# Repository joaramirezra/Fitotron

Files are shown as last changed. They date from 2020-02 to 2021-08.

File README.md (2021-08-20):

# Recamara de ambiente Controlado para germinar semillas de cannabis(Fitotron) 
### version : 0.2
### Fecha : 01/08/2021

**Antecedentes:** En el marco de la discusión de la propuesta del proyecto de ley sobre  regulación del consumo de cannabis con usos recreativo en Colombia, se han desarrollado debates en variados ámbitos algunos versan alrededor del cultivo,iacto economico, social, cultural  entre otros, por lo anterior se desarrolla un sistema de germinacion de semillas de cannabis, para poder impactar de manera positiva las primeras fases de la planta y con ellos contribuir en fases posteriores de crecimiento y cosecha.

**Descripción:**

### Requerimientos

**Hardware:**

- [ESP 8266](https://www.espressif.com/sites/default/files/documentation/0a-esp8266ex_datasheet_en.pdf)
- [Driver Actuadores](http://www.ti.com/lit/ds/symlink/uln2003a.pdf)
- [Sensor Humedad](https://www.sparkfun.com/datasheets/Sensors/Temperature/DHT22.pdf)
- [Raspberry pi]()

**Software:**

- [kicad 5.1.2](https://kicad-pcb.org/download/)
- [inventor 2019](https://www.autodesk.com/education/free-software/inventor-professional)
- [Arduino 18.1](https://www.arduino.cc/en/main/software)

### Colaboradores:
- [Johan Ramirez](https://github.com/joaramirezra)
- [Julio Cárdenas](https://github.com/julio-cardenas)

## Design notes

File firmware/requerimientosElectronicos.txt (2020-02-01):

Procesador : ESP32
Actuadores: 2 humidificadores 5Vdc, 12 ventiadores 12Vdc, 
	    6 luces led 12Vdc, 2 motobombas 12 Vdc, 1 resistencias de 
	    calentamiento 120 Vac
Sensores: 3 dht22 -> temperatura y humedad del aire 5V o 3.3Vdc
	  3 MQ135  -> dioxido de carbono 5 Vdc
	  2 SH2 -> sensor humedad del suelo 3.3Vdc
	  * deben poder encenderse y apagarse en la medición

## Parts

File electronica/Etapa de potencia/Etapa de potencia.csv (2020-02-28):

Reference(s) | Value | LibPart | Footprint
C1 | 100nF | Device:C_Small | Capacitor_SMD:C_0805_2012Metric_Pad1.15x1.40mm_HandSolder
C2, C3 | 10uF | Device:C_Small | Capacitor_SMD:C_0805_2012Metric_Pad1.15x1.40mm_HandSolder
D1 | BTA16 | Device:Q_TRIAC_A1A2G | Package_TO_SOT_THT:TO-220-3_Horizontal_TabDown
J1, J2 | Bornera Resorte | Connector_Generic:Conn_01x08 | potenciaFootprints:BorneraKF141R_8Pins
J3 | Bornera Resorte | Connector_Generic:Conn_01x04 | potenciaFootprints:BorneraKF141R_4Pins
J4 | Bornera 4 pines | Connector:Screw_Terminal_01x04 | TerminalBlock:TerminalBlock_Altech_AK300-4_P5.00mm
J5 | Header | Connector_Generic:Conn_01x04 | Connector_PinHeader_2.54mm:PinHeader_1x04_P2.54mm_Vertical
Q1, Q2, Q3 | MMBT2222 | Transistor_BJT:MMBT3904 | Package_TO_SOT_SMD:SOT-23
R1 | 10K | Device:R_US | Resistor_SMD:R_0805_2012Metric_Pad1.15x1.40mm_HandSolder
R2 | 470 | Device:R_US | Resistor_SMD:R_0805_2012Metric_Pad1.15x1.40mm_HandSolder
R3, R4, R5 | 1K | Device:R_US | Resistor_SMD:R_0805_2012Metric_Pad1.15x1.40mm_HandSolder
R6 | 100 | Device:R_US | Resistor_THT:R_Axial_DIN0411_L9.9mm_D3.6mm_P12.70mm_Horizontal
U1 | ATmega328-PU | MCU_Microchip_ATmega:ATmega328-PU | Package_DIP:DIP-28_W7.62mm
U2, U3 | ULN2003 | Transistor_Array:ULN2003 | Package_SO:SOIC-16W_5.3x10.2mm_P1.27mm
U4 | MOC3031M | Relay_SolidState:MOC3031M | Package_DIP:DIP-6_W7.62mm_LongPads
Y1 | Crystal | Device:Crystal | Crystal:Crystal_SMD_0603-2Pin_6.0x3.5mm

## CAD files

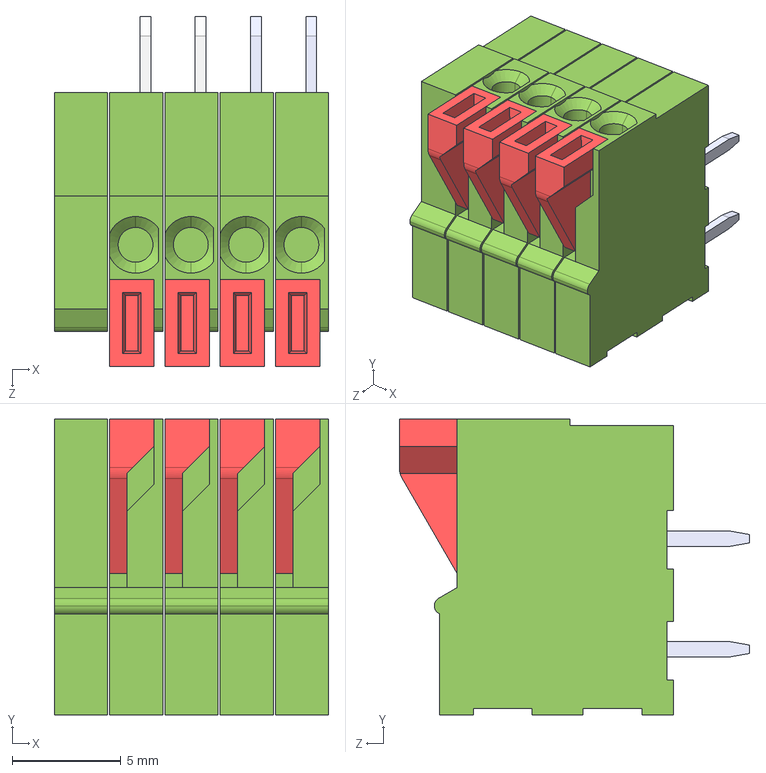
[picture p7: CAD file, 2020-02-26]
electronica/Etapa de potencia/User Library-DG141R-4-2_54.STEP
12.6 x 13.6 x 16.1 mm

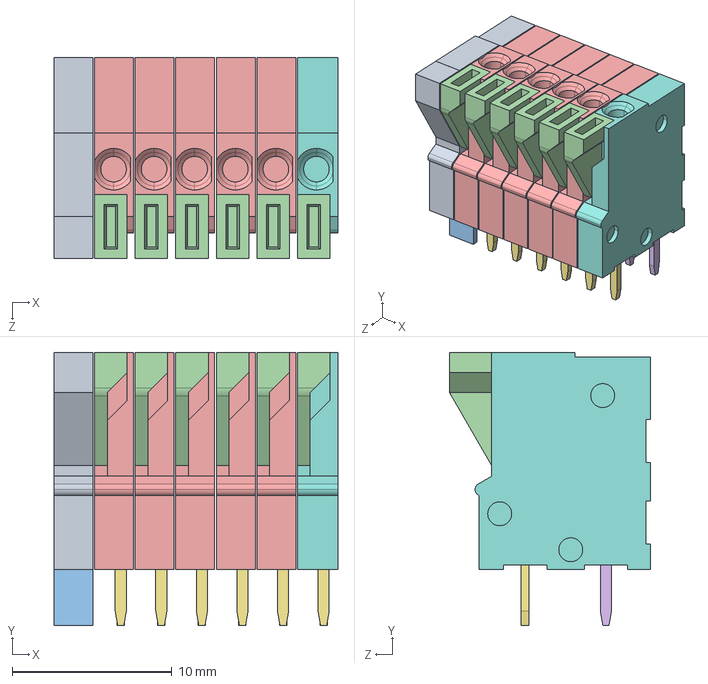
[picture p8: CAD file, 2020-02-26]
electronica/Etapa de potencia/DG141V-4-2.54.STEP
17.8 x 17.1 x 12.6 mm

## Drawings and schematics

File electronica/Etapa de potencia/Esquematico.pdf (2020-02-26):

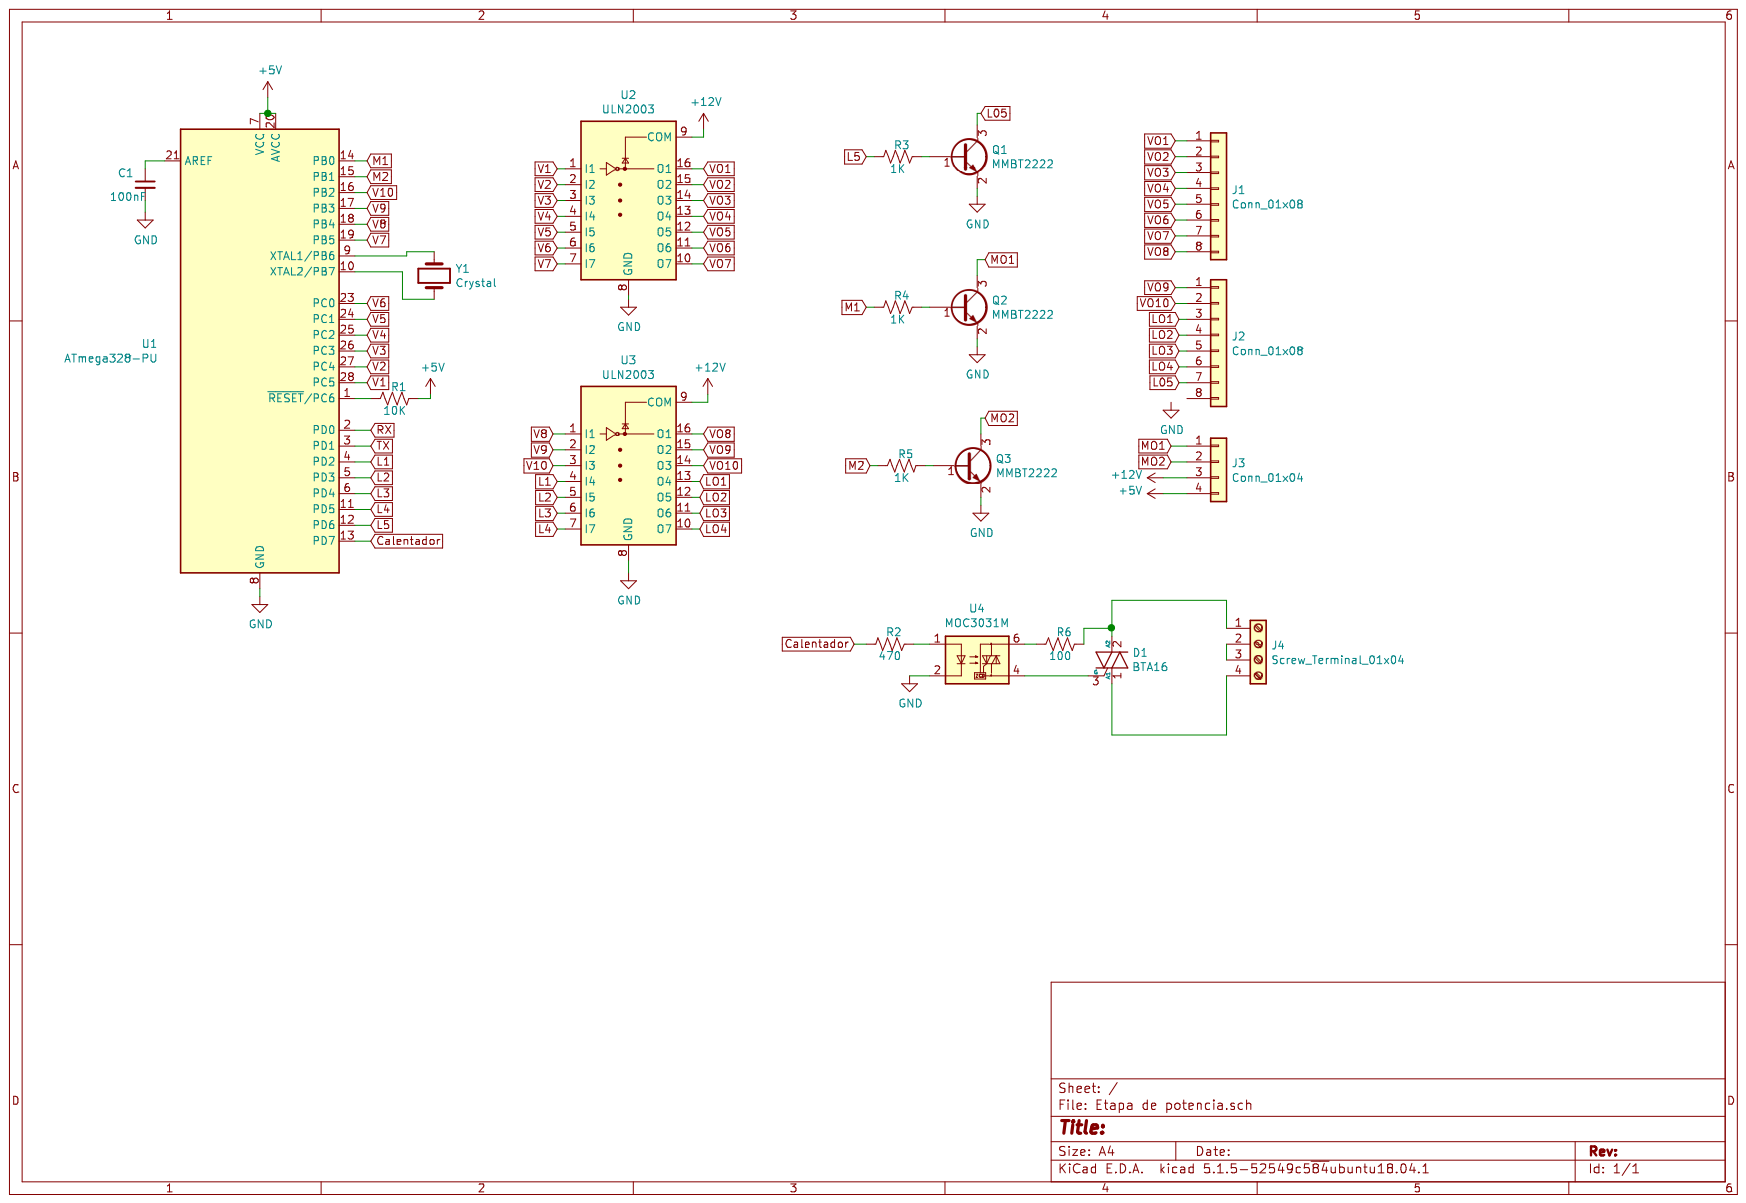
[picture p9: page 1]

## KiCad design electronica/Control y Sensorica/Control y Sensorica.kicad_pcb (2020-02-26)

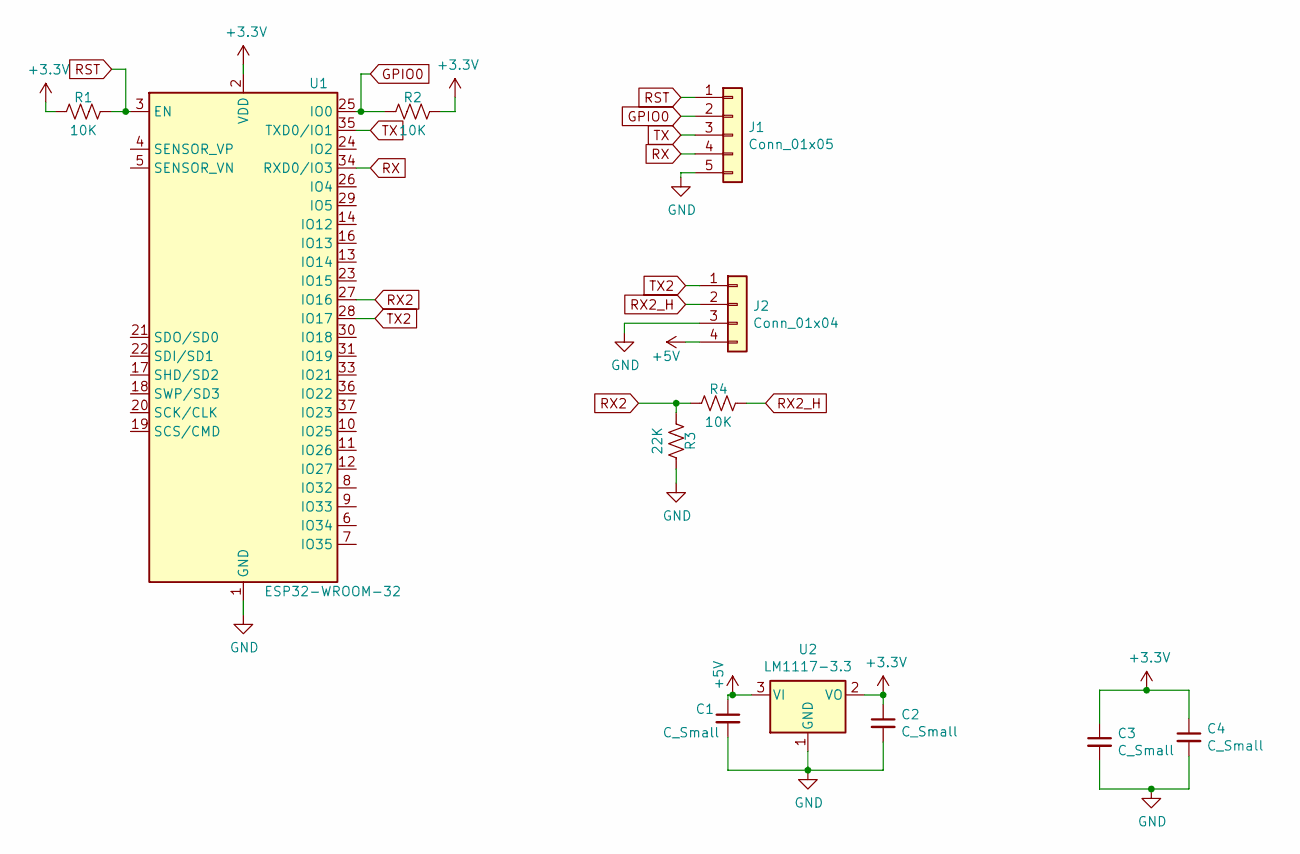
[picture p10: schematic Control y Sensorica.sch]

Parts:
C1, C2, C3, C4: C_Small; C_0805_2012Metric_Pad1.15x1.40mm_HandSolder
J1: Conn_01x05; PinHeader_1x05_P2.54mm_Horizontal
J2: Conn_01x04; PinSocket_1x04_P2.54mm_Vertical
R1, R2, R4: 10K; R_0805_2012Metric_Pad1.15x1.40mm_HandSolder
R3: 22K; R_0805_2012Metric_Pad1.15x1.40mm_HandSolder
U1: ESP32-WROOM-32
U2: LM1117-3.3; TO-252-2

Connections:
+3V3: C2.1, C3.1, C4.1, R1.2, R2.1, U1.2 (VDD), U2.2 (VO)
+5V: C1.1, J2.4, U2.3 (VI)
GND: C1.2, C2.2, C3.2, C4.2, J1.5, J2.3, R3.1, U1.1 (GND), U1.15 (GND), U1.38 (GND), U1.39 (GND), U2.1 (GND)
GPIO0: J1.2, R2.2, U1.25 (IO0)
RST: J1.1, R1.1, U1.3 (EN)
RX: J1.4, U1.34 (RXD0/IO3)
RX2: R3.2, R4.2, U1.27 (IO16)
RX2_H: J2.2, R4.1
TX: J1.3, U1.35 (TXD0/IO1)
TX2: J2.1, U1.28 (IO17)

Board: 2 copper layers, 12 parts (0 on the bottom side), 10 nets, no tracks yet.

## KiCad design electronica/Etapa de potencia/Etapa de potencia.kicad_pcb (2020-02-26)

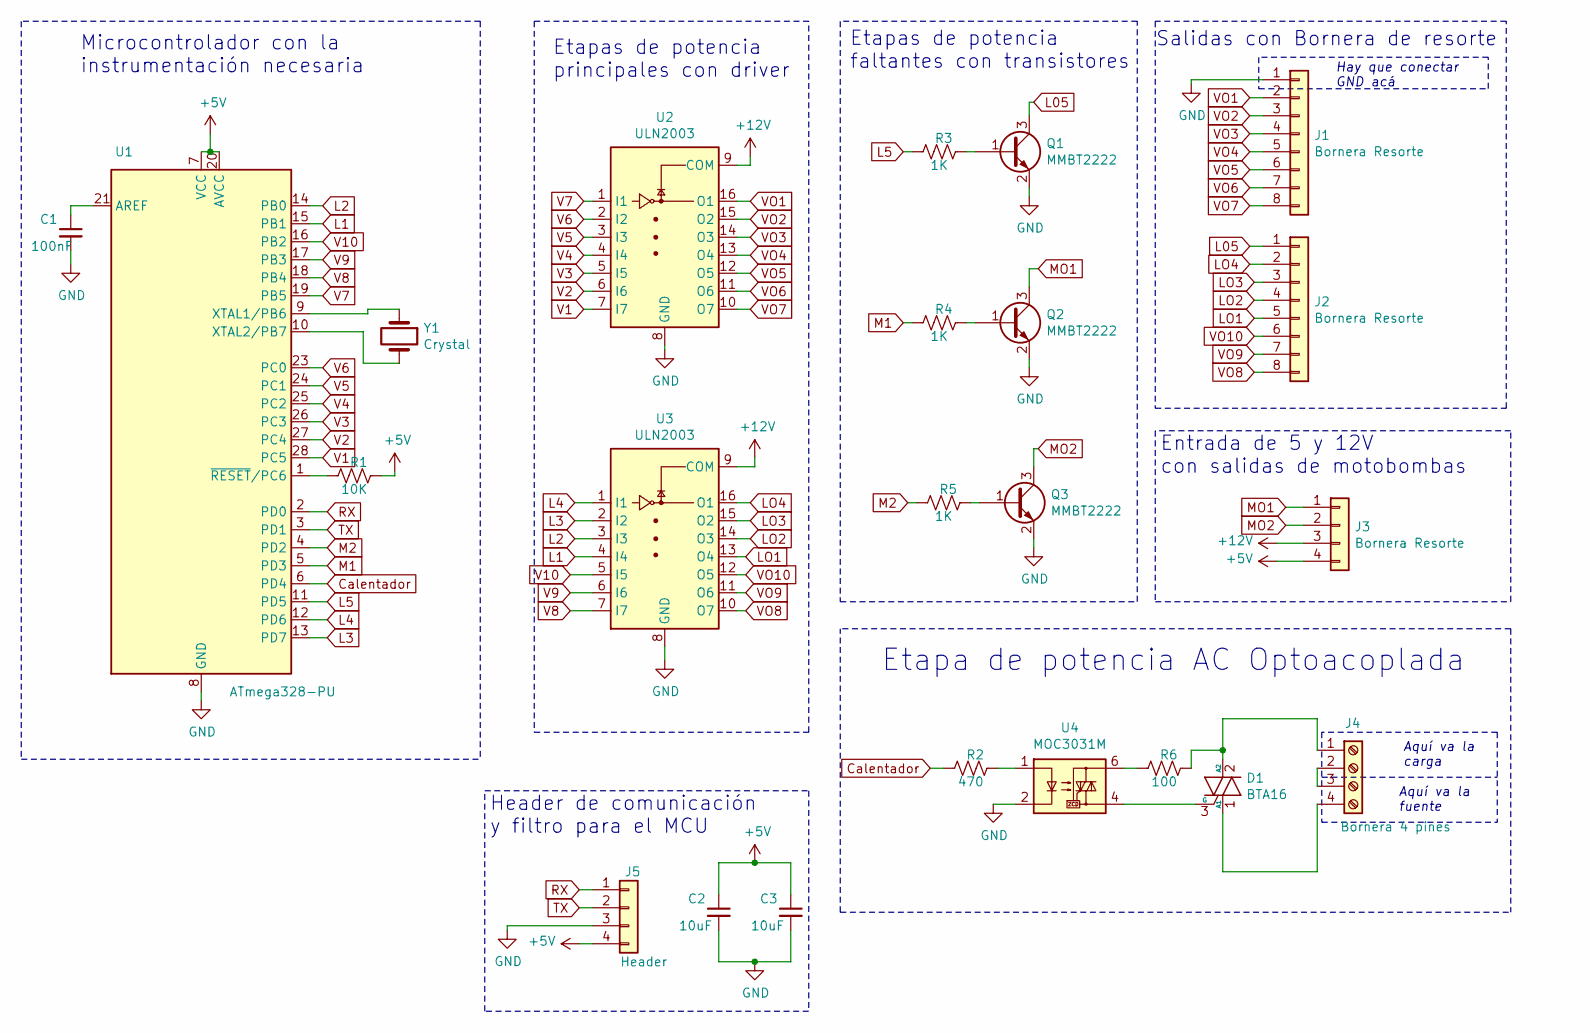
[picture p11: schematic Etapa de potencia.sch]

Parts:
C1: 100nF; C_0805_2012Metric_Pad1.15x1.40mm_HandSolder
C2, C3: 10uF; C_0805_2012Metric_Pad1.15x1.40mm_HandSolder
D1: BTA16; TO-220-3_Horizontal_TabDown
J1, J2: Bornera Resorte; BorneraKF141R_8Pins
J3: Bornera Resorte; BorneraKF141R_4Pins
J4: Bornera 4 pines; TerminalBlock_Altech_AK300-4_P5.00mm
J5: Header; PinHeader_1x04_P2.54mm_Vertical
Q1, Q2, Q3: MMBT2222; SOT-23
R1: 10K; R_0805_2012Metric_Pad1.15x1.40mm_HandSolder
R2: 470; R_0805_2012Metric_Pad1.15x1.40mm_HandSolder
R3, R4, R5: 1K; R_0805_2012Metric_Pad1.15x1.40mm_HandSolder
R6: 100; R_Axial_DIN0411_L9.9mm_D3.6mm_P12.70mm_Horizontal
U1: ATmega328-PU; DIP-28_W7.62mm
U2, U3: ULN2003; SOIC-16W_5.3x10.2mm_P1.27mm
U4: MOC3031M; DIP-6_W7.62mm_LongPads
Y1: Crystal; Crystal_SMD_0603-2Pin_6.0x3.5mm

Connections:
+5V: C2.1, C3.1, J3.4, J5.4, R1.1, U1.7 (VCC), U1.20 (AVCC)
+12V: J3.3, U2.9 (COM), U3.9 (COM)
Calentador: R2.2, U1.6 (PD4)
GND: C1.2, C2.2, C3.2, J1.1, J5.3, Q1.2 (E), Q2.2 (E), Q3.2 (E), U1.8 (GND), U1.22 (GND), U2.8 (GND), U3.8 (GND), U4.2
L1: U1.15 (PB1), U3.4 (I4)
L2: U1.14 (PB0), U3.3 (I3)
L3: U1.13 (PD7), U3.2 (I2)
L4: U1.12 (PD6), U3.1 (I1)
L05: J2.1, Q1.3 (C)
L5: R3.2, U1.11 (PD5)
LO1: J2.5, U3.13 (O4)
LO2: J2.4, U3.14 (O3)
LO3: J2.3, U3.15 (O2)
LO4: J2.2, U3.16 (O1)
M1: R4.2, U1.5 (PD3)
M2: R5.2, U1.4 (PD2)
MO1: J3.1, Q2.3 (C)
MO2: J3.2, Q3.3 (C)
unnamed: C1.1, U1.21 (AREF)
unnamed: D1.1 (A1), J4.4
unnamed: D1.2 (A2), J4.1, R6.1
unnamed: D1.3 (G), U4.4
unnamed: J4.2, J4.3
unnamed: Q1.1 (B), R3.1
unnamed: Q2.1 (B), R4.1
unnamed: Q3.1 (B), R5.1
unnamed: R1.2, U1.1 (~RESET~/PC6)
unnamed: R2.1, U4.1
unnamed: R6.2, U4.6
unnamed: U1.9 (XTAL1/PB6), Y1.1
unnamed: U1.10 (XTAL2/PB7), Y1.2
RX: J5.1, U1.2 (PD0)
TX: J5.2, U1.3 (PD1)
V1: U1.28 (PC5), U2.7 (I7)
V2: U1.27 (PC4), U2.6 (I6)
V3: U1.26 (PC3), U2.5 (I5)
V4: U1.25 (PC2), U2.4 (I4)
V5: U1.24 (PC1), U2.3 (I3)
V6: U1.23 (PC0), U2.2 (I2)
V7: U1.19 (PB5), U2.1 (I1)
V8: U1.18 (PB4), U3.7 (I7)
V9: U1.17 (PB3), U3.6 (I6)
V10: U1.16 (PB2), U3.5 (I5)
VO1: J1.2, U2.16 (O1)
VO2: J1.3, U2.15 (O2)
VO3: J1.4, U2.14 (O3)
VO4: J1.5, U2.13 (O4)
VO5: J1.6, U2.12 (O5)
VO6: J1.7, U2.11 (O6)
VO7: J1.8, U2.10 (O7)
VO8: J2.8, U3.10 (O7)
VO9: J2.7, U3.11 (O6)
VO10: J2.6, U3.12 (O5)

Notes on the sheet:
Etapa de potencia AC Optoacoplada
Salidas con Bornera de resorte
Hay que conectar GND acá
Entrada de 5 y 12V con salidas de motobombas
Etapas de potencia faltantes con transistores
Etapas de potencia principales con driver
Aquí va la fuente
Aquí va la carga
Microcontrolador con la instrumentación necesaria
Header de comunicación y filtro para el MCU

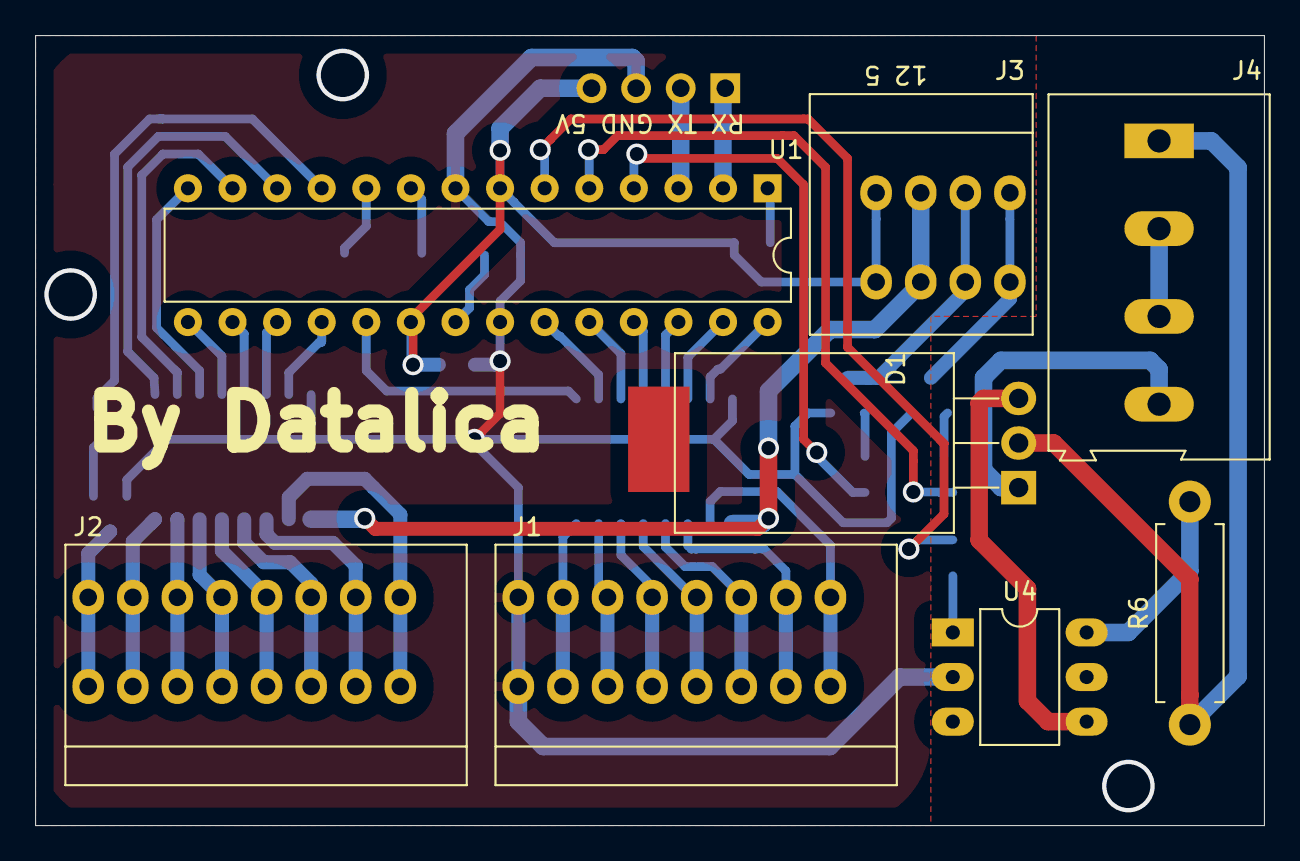
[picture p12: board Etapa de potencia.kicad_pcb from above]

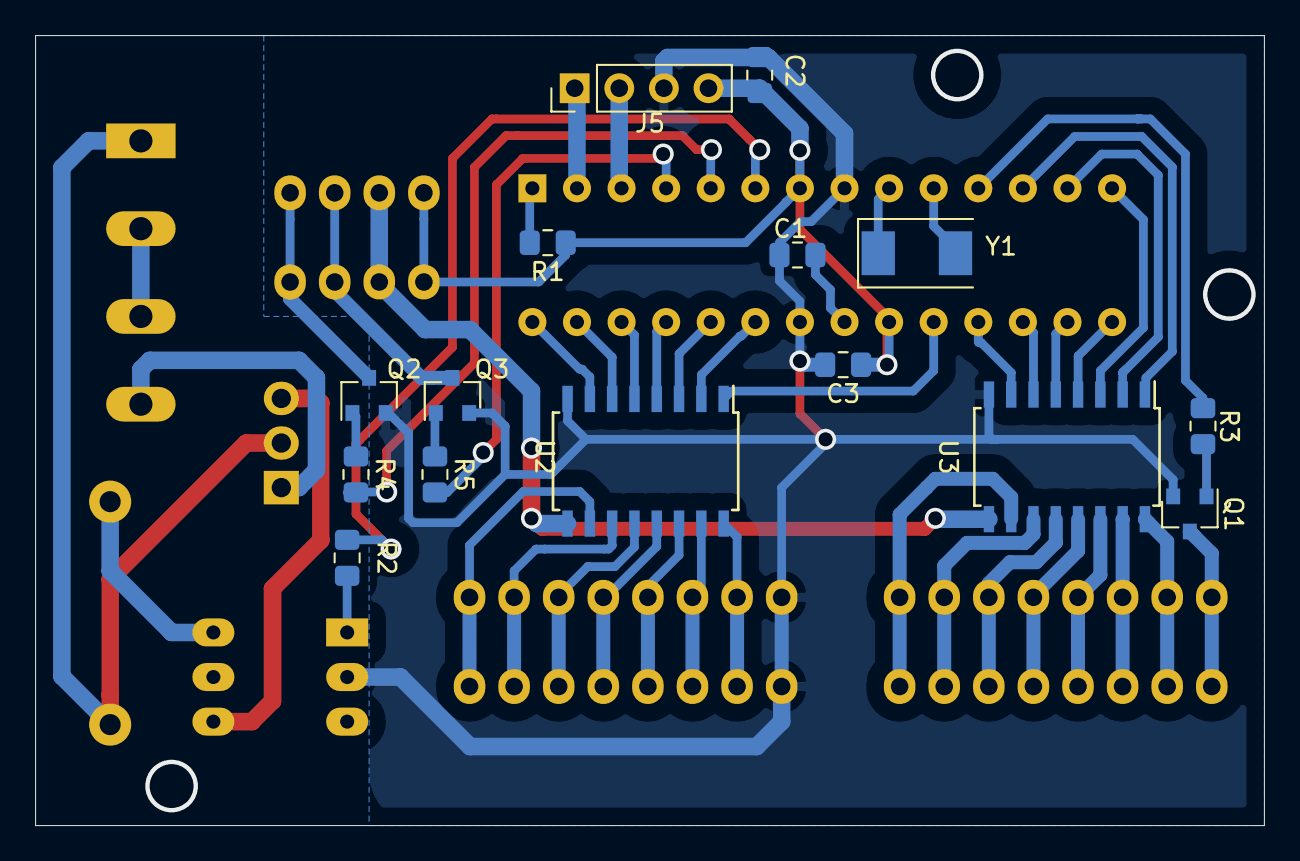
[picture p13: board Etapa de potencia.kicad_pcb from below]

Board: 2 copper layers, 70.0 x 45.0 mm, 23 parts (15 on the bottom side), 53 nets.

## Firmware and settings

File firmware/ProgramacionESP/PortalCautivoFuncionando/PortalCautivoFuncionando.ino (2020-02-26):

//Download all required header filers from circuitdigest.com 
#include <ESP8266WiFi.h>
#include "./DNSServer.h"  
#include <ESP8266WebServer.h>

const byte        DNS_PORT = 53;          // 53 is set as DNS port
IPAddress         apIP(10, 10, 10, 1);    // Network Server
DNSServer         dnsServer;              // DNS server object
ESP8266WebServer  webServer(80);          // Webserver object 

int pinMotor = D8; //Pin defanition - Relay will be connected to GPIO-0
int pinLuces = D4; //Pin defanition - Relay will be connected to GPIO-0
int pinVenta = D6; //Pin defanition - Relay will be connected to GPIO-0
int pinHumis = D2; //Pin defanition - Relay will be connected to GPIO-0

/*START OF HMTL CODE*/
String style_detials =  //This String defines the style attributes for webpage
   "<style type=\"text/css\">"
   " body{background-color: #a69695;}"
    "button{display: inline-block;}"
    "#buttons{text-align: center;}"

    ".controllButtons{"
     " margin-top: 15px;"
      "margin-left: 5px;"
      "background-color: white;"
      "padding: 10px;"
      "border:1px solid black;"
      "border-radius: 10px;"
      "cursor: pointer;"
      "font-size: 14px;"
    "}"

    ".controllButtons:hover{"
     " background-color: orange;"
      "padding: 10px;"
      "border:1px solid black;"
      "border-radius: 10px;"
      "cursor: pointer;"
      "font-size: 14px;"
    "}"

    "@media only screen and (max-width: 700px) {"
     " button{"
      "  display: block;"
      "}"
      "#buttons{"
       " margin-top: 10%;"
        "margin-left: 35%;"
      "}"
       " .controllButtons{"
        "  margin-top: 15px;"
        "margin-left: 5px;"
        "background-color: white;"
        "padding: 15px;"
        "border:1px solid black;"
        "border-radius: 10px;"
        "cursor: pointer;"
        "font-size: 16px;"
      "}"

      ".controllButtons:hover{"
       " background-color: orange;"
        "padding: 15px;"
        "border:1px solid black;"
        "border-radius: 10px;"
        "cursor: pointer;"
        "font-size: 16px;"
      "}"
    "}"

  "</style>";

String Home_Screen = "" //Page 1 - Home Screen HTML code
                      "<!DOCTYPE html><html>"
                      "<head><meta name=\"viewport\" content=\"width=device-width, initial-scale=1\">"
                      "<h4>Bienvenido al fitotron</h4>"
                      + style_detials +
                      "<div id=\"buttons\">"
                      "<h4>Ventiladores Entrada</h4>"
                      "<a style=\"text-decoration:none;\" href=\"motor1\"><button id=\"switchLight1\" class=\"controllButtons\">Encender</button></a>"
                      "<a style=\"text-decoration:none;\" href=\"motor2\"><button id=\"switchLight2\" class=\"controllButtons\">Apagar</button></a>"
                      "<h4>Ventiladores Salida</h4>"
                      "<a style=\"text-decoration:none;\" href=\"venta1\"><button id=\"switchLight3\" class=\"controllButtons\">Encender</button></a>"
                      "<a style=\"text-decoration:none;\" href=\"venta2\"><button id=\"switchLight3\" class=\"controllButtons\">Apagar</button></a>"
                      "<h4>Luces superior </h4>"
                      "<a style=\"text-decoration:none;\" href=\"luces1\"><button id=\"switchLight3\" class=\"controllButtons\">Encender</button></a>"
                      "<a style=\"text-decoration:none;\" href=\"luces2\"><button id=\"switchLight3\" class=\"controllButtons\">Apagar</button></a>"
                      "<h4>Humidificadores</h4>"
                      "<a style=\"text-decoration:none;\" href=\"humis1\"><button id=\"switchLight3\" class=\"controllButtons\">Encender</button></a>"
                      "<a style=\"text-decoration:none;\" href=\"humis2\"><button id=\"switchLight3\" class=\"controllButtons\">Apagar</button></a>"
                      
                      "</div>"
                      "<body>"
                      "</body></html>";

/*END OF HMTL CODE*/                    
                      
void setup() {
  pinMode(LED_BUILTIN, OUTPUT);                           // LED pin as output for indication 
  pinMode(pinMotor, OUTPUT);                                // GPIO pin as output for Relay control 
  pinMode(pinLuces, OUTPUT);                                // GPIO pin as output for Relay control 
  pinMode(pinVenta, OUTPUT);                                // GPIO pin as output for Relay control 
  pinMode(pinHumis, OUTPUT);                                // GPIO pin as output for Relay control 
    
  WiFi.mode(WIFI_AP);                                     // Set ESP in AP mode
  WiFi.softAPConfig(apIP, apIP, IPAddress(255, 255, 255, 0));
  WiFi.softAP("Fitotron");                                // Nombre AccesPoint

  dnsServer.start(DNS_PORT, "*", apIP);

  webServer.onNotFound([]() {
    webServer.sendHeader("Location", String("http://www.circuitdigest-automation.com/home.html"), true); //Open Home screen by default 
    webServer.send ( 302, "text/plain", "");
  });
  
  webServer.on("/home.html", []() {                       
    webServer.send(200, "text/html", Home_Screen);        // Mensaje de inicio
  });

//Motor on
  webServer.on("/motor1", [](){                         // Si el boton es presionado
       digitalWrite(pinMotor, HIGH);                      // Turn off Relay 
       webServer.send(200, "text/html", Home_Screen);        // Display this screen 
  });

//Motor off
  webServer.on("/motor2", [](){                         // If turn off Button is pressed 
       digitalWrite(pinMotor, LOW);
       webServer.send(200, "text/html", Home_Screen);     // Display this screen
  });
//Luces on
webServer.on("/luces1", [](){                         // If turn off Button is pressed 
       digitalWrite(pinLuces, HIGH);
       webServer.send(200, "text/html", Home_Screen);     // Display this screen
  });
//Luces off
webServer.on("/luces2", [](){                         // If turn off Button is pressed 
       digitalWrite(pinLuces, LOW);
       webServer.send(200, "text/html", Home_Screen);     // Display this screen
  });
//Venta on
webServer.on("/venta1", [](){                         // If turn off Button is pressed 
       digitalWrite(pinVenta, HIGH);
       webServer.send(200, "text/html", Home_Screen);     // Display this screen
  });
//Venta off
webServer.on("/venta2", [](){                         // If turn off Button is pressed 
       digitalWrite(pinVenta, LOW); 
       webServer.send(200, "text/html", Home_Screen);     // Display this screen
  });
//Humi on
webServer.on("/venta1", [](){                         // If turn off Button is pressed 
       digitalWrite(pinHumis, HIGH);
       webServer.send(200, "text/html", Home_Screen);     // Display this screen
  });
//Humi off
webServer.on("/venta2", [](){                         // If turn off Button is pressed 
       digitalWrite(pinHumis, LOW);
       webServer.send(200, "text/html", Home_Screen);     // Display this screen
  });


  webServer.begin();                                      // Iniciar servidor
}

void loop() {
  dnsServer.processNextRequest();
  webServer.handleClient();
}

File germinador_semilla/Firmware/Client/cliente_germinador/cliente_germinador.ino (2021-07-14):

#include <ESP8266WiFi.h>
#include <PubSubClient.h>

// Update these with values suitable for your network.

const char* ssid = "KEIDY";
const char* password = "#Salmon47@#797*";
//const char* mqtt_server = "broker.mqtt-dashboard.com";

WiFiClient espClient;
PubSubClient client(espClient);
long lastMsg = 0;
char msg[50];
int value = 0;

void setup() {
  pinMode(BUILTIN_LED, OUTPUT);     // Initialize the BUILTIN_LED pin as an output 
  Serial.begin(9600);
  setup_wifi();
  client.setServer(mqtt_server, 1883);
  client.setCallback(callback);
}

void setup_wifi() {

  delay(10);
  // We start by connecting to a WiFi network
  Serial.println();
  Serial.print("Connecting to ");
  Serial.println(ssid);

  WiFi.begin(ssid, password);

  while (WiFi.status() != WL_CONNECTED) {
    delay(500);
    Serial.print(".");
  }

  Serial.println("");
  Serial.println("WiFi connected");
  Serial.println("IP address: ");
  Serial.println(WiFi.localIP());
}

void callback(char* topic, byte* payload, unsigned int length) {
  Serial.print("Message arrived [");
  Serial.print(topic);
  Serial.print("] ");
  for (int i = 0; i < length; i++) {
    Serial.print((char)payload[i]);
  }
  Serial.println();--
  if ((char)payload[0] == '1') {
    digitalWrite(BUILTIN_LED, LOW);   
  } else {
    digitalWrite(BUILTIN_LED, HIGH);  // Turn the LED off by making the voltage HIGH
  }

}

void reconnect() {
  // Loop until we're reconnected
  while (!client.connected()) {
    Serial.print("Attempting MQTT connection...");
    // Attempt to connect
    if (client.connect("ESP8266Client")) {
      Serial.println("connected");
      // Once connected, publish an announcement...
      client.publish("outTopic", "hello world");
      // ... and resubscribe
      client.subscribe("inTopic");
    } else {
      Serial.print("failed, rc=");
      Serial.print(client.state());
      Serial.println(" try again in 5 seconds");
      // Wait 5 seconds before retrying
      delay(5000);
    }
  }
}



void configurar_pines(){
  
  
  }



void loop() {

  if (!client.connected()) {
    reconnect();
  }
  client.loop();

  long now = millis();
  if (now - lastMsg > 2000) {
    lastMsg = now;
    ++value;
    snprintf (msg, 75, "hello world #%ld", value);
    Serial.print("Publish message: ");
    Serial.println(msg);
    client.publish("outTopic", msg);
  }
}

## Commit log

2020-02-03 Electronica 0.5
    [EsquematicoFitotron.sch]
2020-02-06 Adding power stage
    [Etapa de potencia.kicad_pcb, Etapa de potencia.sch]
2020-02-08 Power Stage PCB ready to revision
    [DG141V-4-2.54.STEP, Etapa de potencia.kicad_pcb, Etapa de potencia.sch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]
2020-02-08 Adding a Control Stage baseline
    [Control y Sensorica.kicad_pcb, Control y Sensorica.sch, Etapa de potencia.kicad_pcb]
2020-02-21 Programacion de la comunicacion entre el esp y el arduino, ademas se incluye la medicion de varaibles con el ESP
2020-02-21 funcina los tres sensores DHT22
2020-02-23 basic dashboard with firebase
    [Etapa de potencia.csv, Etapa de potenciaV1.csv]
2020-02-26 adding dynamic chart baseline
    [Etapa de potencia.csv, Etapa de potenciaV1.csv]
2021-07-10 simple control interface
    [measures_humidity.csv, measures_light.csv, measures_temperatures.csv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]
2021-07-13 something new mqtt init
    [parameters.csv]
2021-08-18 v0 fitotron
    [parameters.csv]
